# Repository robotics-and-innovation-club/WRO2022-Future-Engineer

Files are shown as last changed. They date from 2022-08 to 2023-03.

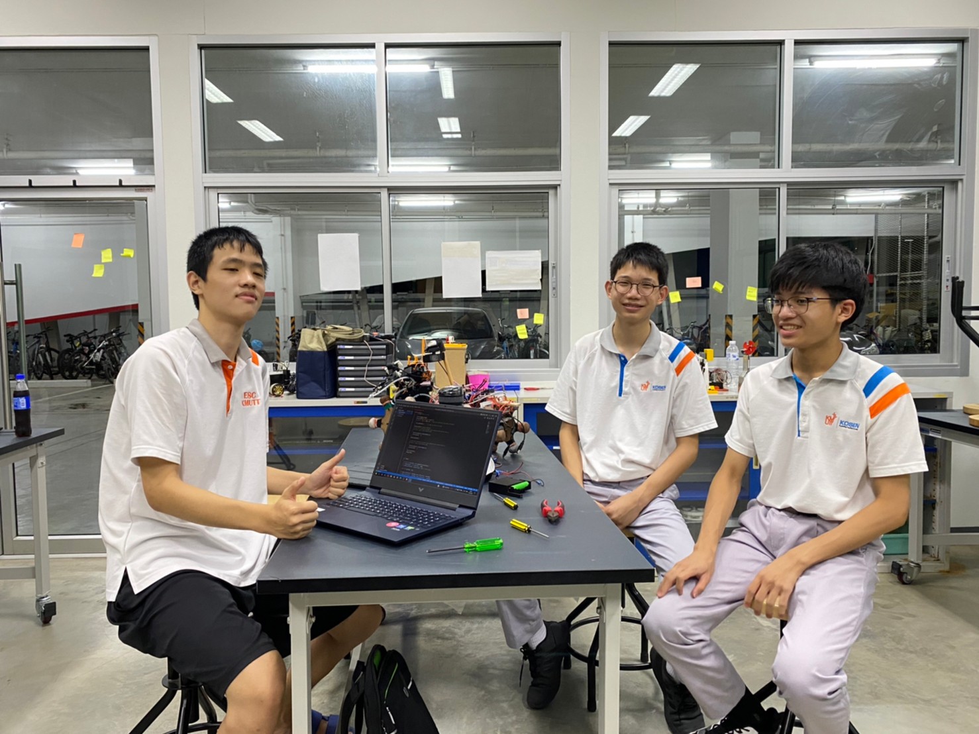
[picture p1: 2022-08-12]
team-photos/Funny Photo.jpg

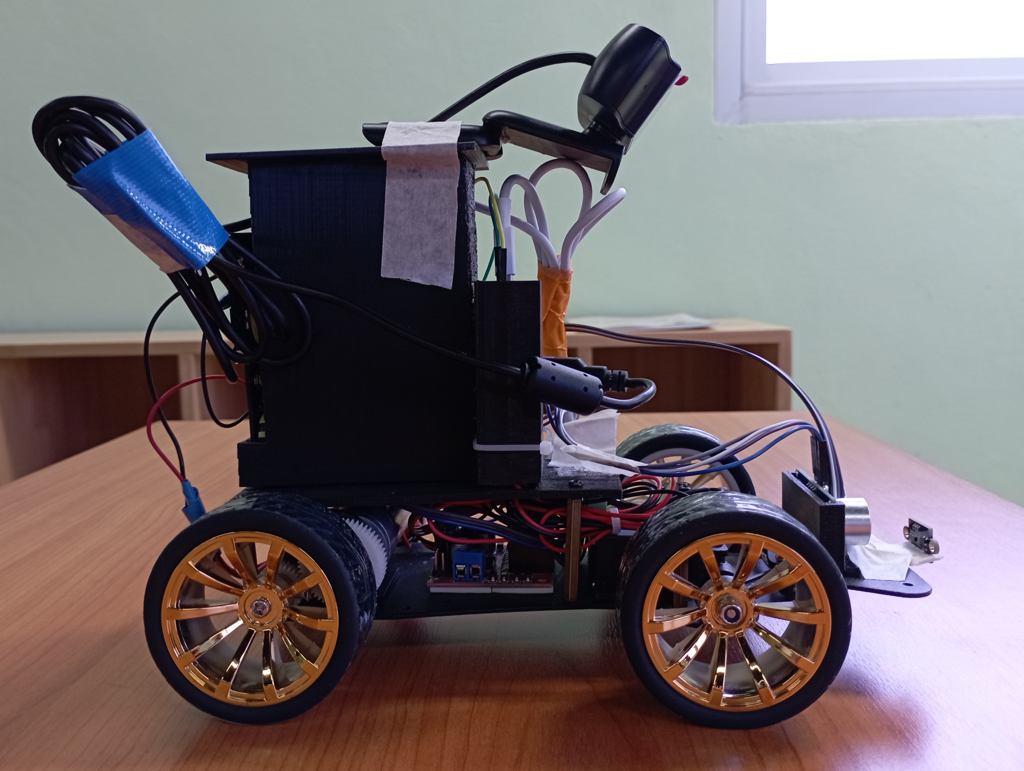
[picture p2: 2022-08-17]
vehicle-photos/LEFT.jpg

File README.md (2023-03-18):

# Teams from the Robotics and Innovation Club (RIC)
Darunsikkhalai School (Engineering-Science Classroom & KOSEN KMUTT)

## Our Teams
- Kitsada      Doungjitjaroen  Supervisor / Assistance
- Theekhathat  Wongsubsantati  Member
- Theeraphat   Thongbai        Member
- Nattavee     Sunitsakul      Member

## Contents
- ```models``` include 3D-printed replicas of our car's parts.
- ```src``` contain all of the source code of our vehicle. (Python source code)
- ```schemes``` contains all of our schematic diagrams of the electromechanical parts that show all the parts (motors, electronics, and other electromechanical components) used in the vehicle and their connections.
- ```team-photos``` contains two images of our team (an official photo and one funny photo with all of our team members)
- ```vehicle-photos``` contains 6 photos of the vehicle (from every side, from top and bottom)
- ```video``` contains a link to a video on YouTube that demonstrates how our vehicle operates.

## Introduction
How can we control electronics with the Raspberry Pi 4? We use the GPIOZERO library to control the GPIO pins of the Raspberry Pi, so that we can control motors and servos. Thanks to the hardware PWM of the Raspberry Pi 4 Model B, it helps our servo motor turn at an accurate angle as well as control the speed of the motor accurately.

How can we make the car go straight? We use computer vision to detect the environment. Then we can approximate how far the car is from the environment.

We use HSV colour space, and then we find a range of colours in the field that we will see in the competition. We need to configure the upper and lower colors, such as orange, blue, black, and white.

In the side environment, we use our upper and lower HSV of black walls. We find the filter black pixels in the upper and lower range. After that, we will filter the blue line out of this frame so that it has more accuracy in detaching black pixels of color.

On the floor, we use the same method to detect blue and orange lines. We use the upper and lower range of orange and blue colors that we found, then detect if the area has more than one consistency value that we researched to filter the error detection.

We also use computer vision to detect which turn we want when the car is initial. This method helps us go in a clockwise and counter-clockwise direction. without a struggle in any direction.

Next, we use data that our computer vision detected before to make a decision to turn left or right by how many degrees or go straight with some speed. We also use data from our 2 distance sensors to help make decisions more accurately on when to turn hard and when to stop.

Then, we use the computer vission to detect the line and count how many rounds have passed by, so that we can control how many rounds we want the car to drive automatically.

### How to use
1. Prepare all electronic parts and machanic parts
2. Bring your Raspberry Pi 4 Model B, then [install Raspberry Pi OS (64-bit)](https://github.com/robotics-and-innovation-club/WRO2022-Future-Engineer#how-to-install-raspberry-pi-os)
3. Install Python 3.10.5 and pip3
4. Install all of required libraries (GPIOZERO, openCV, adafruit-circuitpython-vl53l0x)
5. [Enable I2C](https://github.com/robotics-and-innovation-club/WRO2022-Future-Engineer/blob/main/README.md#how-to-enable-i2c)
6. Enable Hardware PWM, by run ```sudo systemctl enable pigpiod``` in terminal.
7. git clone this github repository
8. open terminal and run ```cd WRO2022-FUTURE-ENGINEER/src```
9. run ```sudo python main1.py``` or ```sudo python main2.py```

## Software / Program
All of our source code is in ```src``` directory. All of it is Python source code.

Our software mainly uses GPIOZERO and openCV libraries. With GPIOZERO, we use this library to control servo motors and motors. With openCV, we use this library to do computer vision.

```Actuator.py``` we use hardware PWM of the Raspberry Pi 4 Model B, so we need to run ```sudo systemctl enable pigpiod``` to enable hardware PWM to work (every time the Raspberry Pi boots it will start pigpiod services automatically).

```Radar_Distance_Sensor.py``` we use for getting the distance from the Radar Distance Sensor (VL53L0X). In the VL53L0X class, the get_distance method will return the distance in centimeters.

### How to install Raspberry Pi OS
1. go to ```https://www.raspberrypi.com/software/``` website, then if you are Windows user click```Download for Windows```, if you are macOS user click```Download for macOS```, if you are Ubuntu use click```Download for Ubuntu for x86```, but if you are Raspberry Pi OS user, type ```sudo apt install rpi-imager``` in a Terminal window.
2. Choose OS, In this car we use ```Raspberry Pi OS (64-bit)```
3. Choose Storage (SD-CARD)
4. (OPTIONAL) If you prefer to configure anything before installing the OS to storage, you can configure it by click ```Advcance Option``` or the gear sign (on the bottom left of the window).
5. Click ```Write```

### How to enable I2C
1. open terminal
2. type ```sudo raspi-config```
3. select ```Interfacing Options```
4. select ```I2C```
5. select ```<Yes>```
6. select ```Ok```
7. If it requires you to reboot, select ```<Yes>```

## Models
- ```base with nut hole.STL``` The STL file is the base component that will be used to attach the electronic mounter component to the vehicle base.
- ```step down mount.STL``` This is the component that will be mounted to the electronic mounter base. This is used to insert a step-down DC to DC converter.

## Electronic
- Raspberry Pi 4 Model B (OS : Raspberry Pi OS 64-bits) 1 ea.
- Battery (18650 Lithium-ion battery) 3 ea.
- USB HD Camera (720p camera) 1 ea.
- DC to DC step down converter (from 9VDC-36VDC to 5VDC-3A) 1 ea.
- Motor Driver Module (L298N) 1 ea.
- DC Motor (12VDC) 1 ea.
- Servo Motor (MG996R) 1 ea.
- Ultrasonic sensor 1 ea.
- Radar Distance sensor 1 ea.

All electronic components are wired as shown in schematic diagrams in ```schemes``` directory.
In ```schemes``` directory, ```diagram_fritzing.png``` is the property diagram from the Fritzing program, and ```Easy Diagram.pdf``` is an easy diagram of our circuit.

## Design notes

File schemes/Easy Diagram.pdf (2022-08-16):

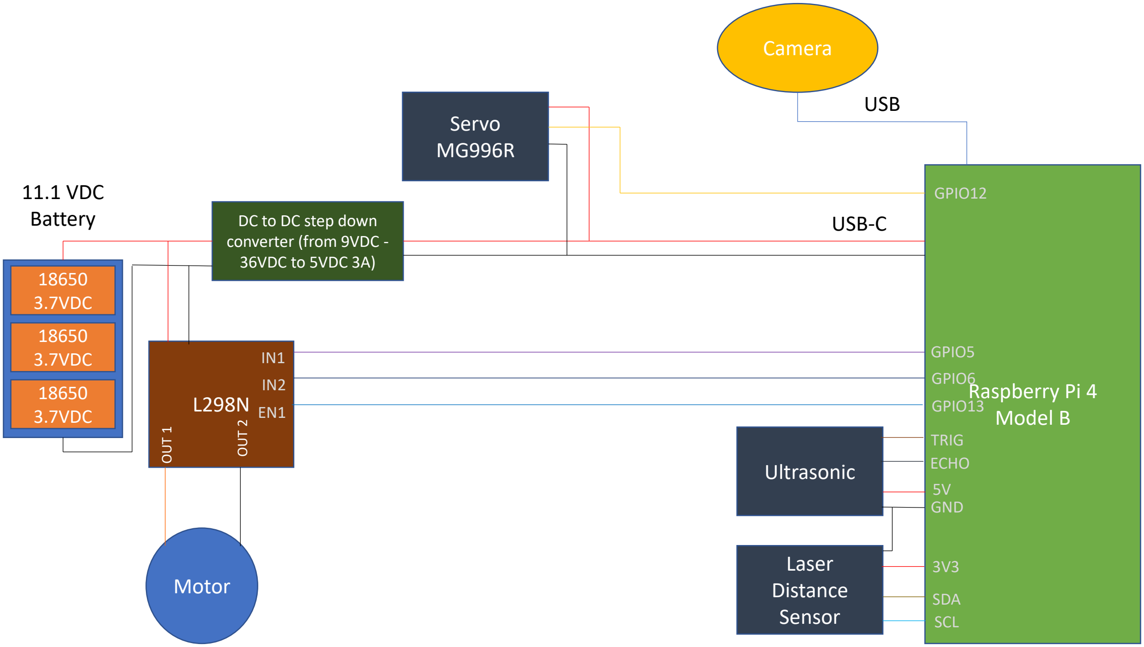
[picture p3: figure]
Raspberry Pi; Model; Camera; USB; 18650 3.7VDC; DC to DC step down converter (from 9VDC; 36VDC to 5VDC 3A); 11.1 VDC Battery; Motor; Servo MG996; OUT 1; OUT 2; GPIO12; GPIO5; GPIO6; GPIO13; Ultrasonic; Laser Distance Sensor; GND; SDA SCL; TRIG ECHO

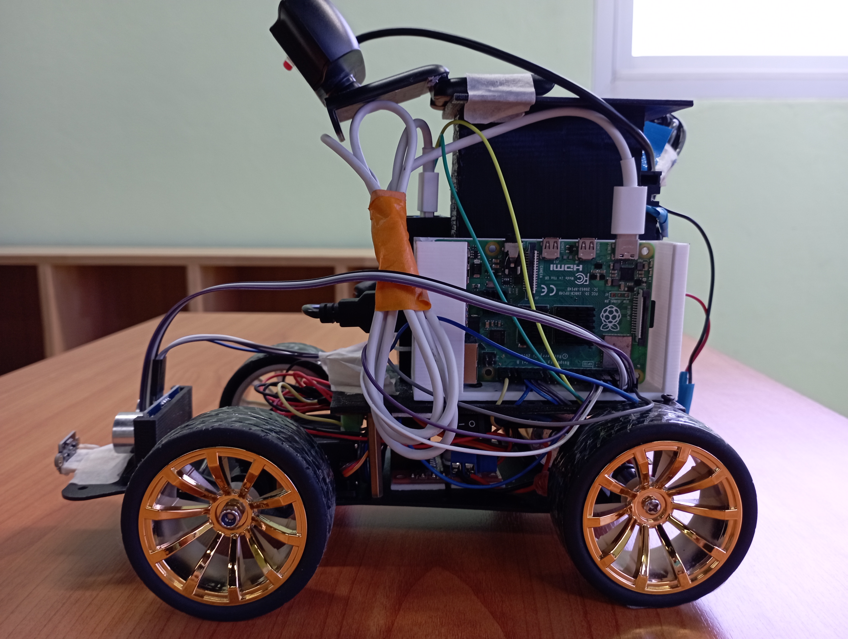
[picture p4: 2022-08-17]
vehicle-photos/RIGHT.jpg

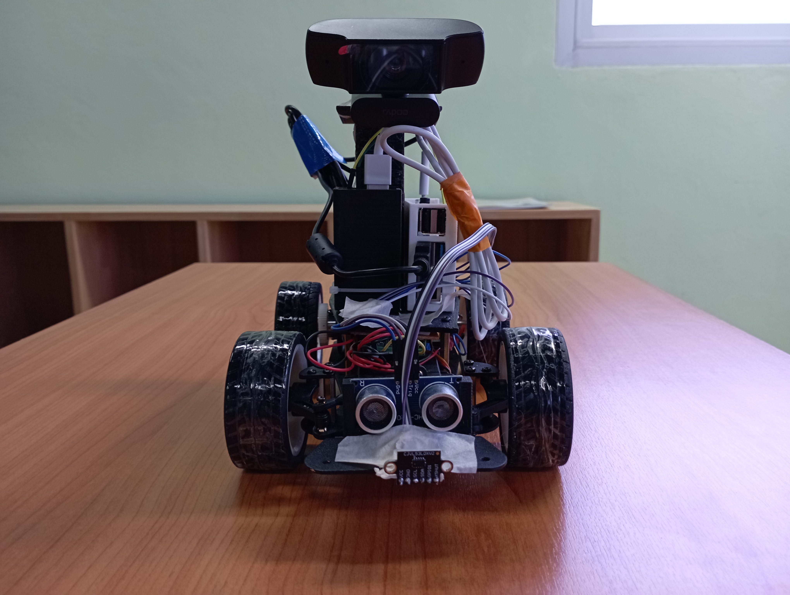
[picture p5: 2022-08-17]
vehicle-photos/FRONT.jpg

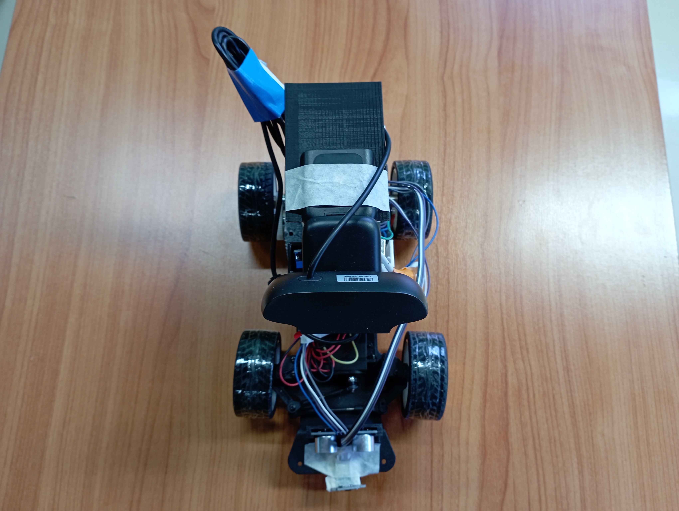
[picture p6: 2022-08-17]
vehicle-photos/TOP.jpg

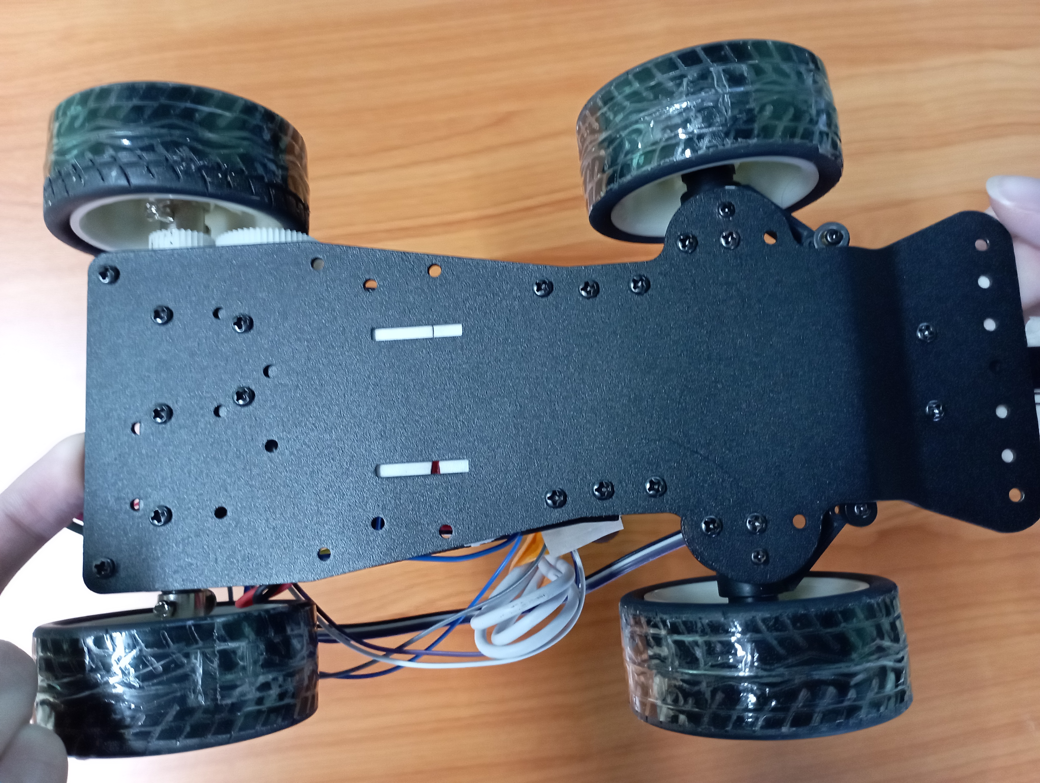
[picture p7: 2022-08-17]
vehicle-photos/BOTTOM.jpg

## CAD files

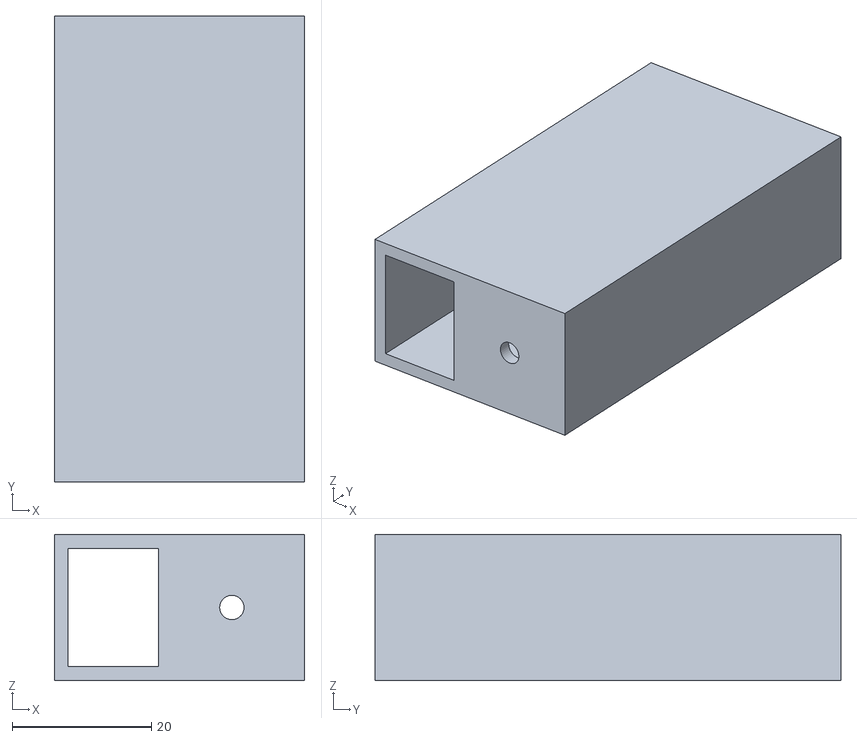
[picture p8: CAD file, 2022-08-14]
models/step down mount.STL
36.0 x 67.0 x 21.0

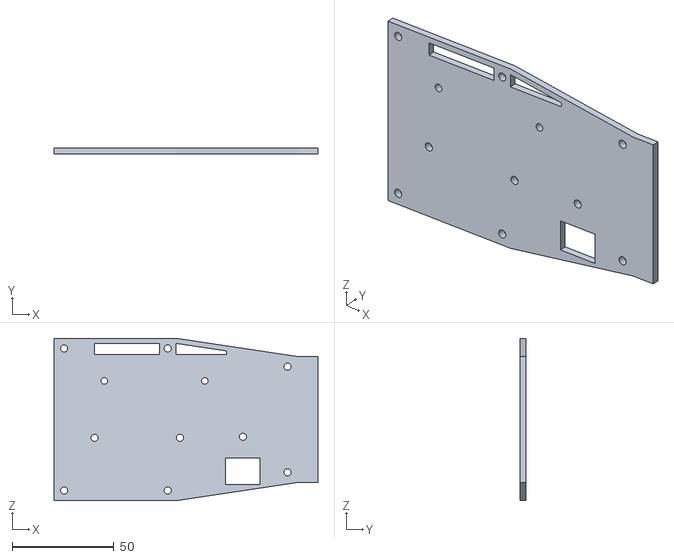
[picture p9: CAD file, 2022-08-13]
models/base with nut hole.STL
130.0 x 3.00 x 80.0

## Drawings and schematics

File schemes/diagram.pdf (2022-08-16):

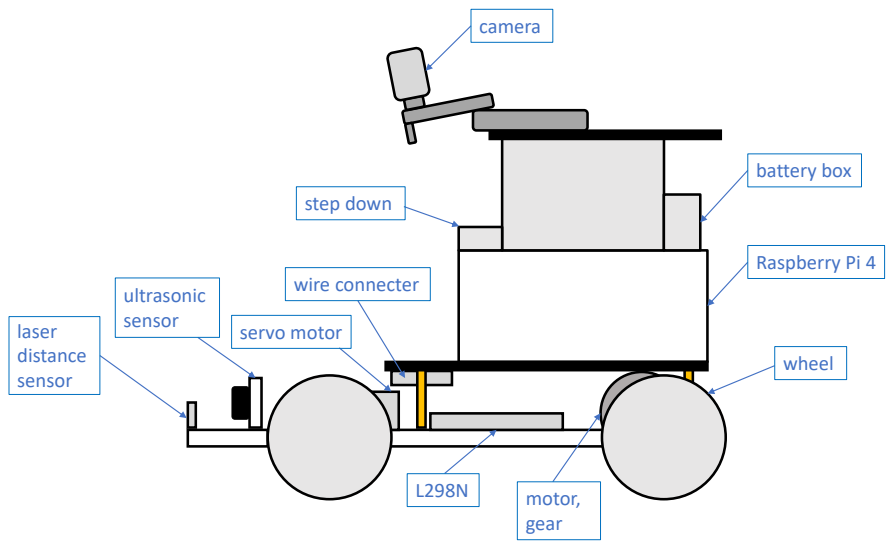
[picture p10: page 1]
camera; Raspberry Pi 4; battery box; wheel; motor, gear; servo motor; ultrasonic sensor laser; distance sensor; wire connecter; step down

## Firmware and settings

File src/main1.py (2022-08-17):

import gpiozero as gpio
from gpiozero.pins.pigpio import PiGPIOFactory
import cv2
import numpy as np
import time
from gpiozero import DistanceSensor
from Actuator import *
from Ultrasonic import *

safe = 40
e_old = None
count = 0

lowBl = np.array([111, 80, 78]) 
upBl = np.array([179, 255, 255])

lowOl = np.array([0, 38, 145]) 
upOl = np.array([179, 255, 255])

lowgreen = np.array([52, 72, 107])  
upgreen = np.array([92, 134, 196])  

lowyellow = np.array([27, 167, 99]) 
upyellow = np.array([42, 255, 231])

lowred = np.array([0, 135, 50])  
upred = np.array([8, 255, 255])

lowred1 = np.array([165, 135, 50]) 
upred1 = np.array([180, 255, 255])

lowfl = np.array([100, 0, 151])
upfl = np.array([179, 255, 255])

lowwall = np.array([0, 0, 0])
upwall = np.array([179, 255, 50])

lowbitb = np.array([100,150,0])
upbitb = np.array([140,255,255])

xright21, yright21 = 430, 230
xright22, yright22 = 640, 270

xleft11, yleft11 = 0, 230
xleft12, yleft12 = 210, 270

xright41, yright41 = 590, 205
xright42, yright42 = 640, 230

xleft31, yleft31 = 0, 205
xleft32, yleft32 = 50, 230

xBl1, yBl1 = 320, 345
xBl2, yBl2 = 390, 405

xOl1, yOl1 = 250, 345
xOl2, yOl2 = 320, 405

xObj1, yObj1 = 110, 140
xObj2, yObj2 = 530, 330

xAbove1 , yAbove1 = 251, 20
xAbove2 , yAbove2 = 389, 190

#[0, 54, 2], [179, 255, 255]

def black_line(frame):  
    global xright21, yright21, xright22, yright22, xAbove1, yAbove1, xAbove2, yAbove2, left_track, right_track, mid_track,yleft11,yleft12, xleft11,xleft12
   
    datb1 = frame[yleft11:yleft12, xleft11:xleft12]
  
    dat1 = cv2.GaussianBlur(datb1, (5, 5), cv2.BORDER_DEFAULT)
 
    hsv = cv2.cvtColor(dat1, cv2.COLOR_BGR2HSV)

    mask1 = cv2.inRange(hsv, lowwall, upwall )

    bmask = cv2.inRange(hsv.copy(), lowOl, upOl)

    bmask1 = cv2.inRange(hsv.copy(), lowbitb, upbitb)

    bmask2 = cv2.inRange(hsv.copy(), lowfl, upfl)

    bmask3 = cv2.bitwise_or(bmask, bmask1)

    bmask4 = cv2.bitwise_or(bmask3, bmask2)

    maskd1 = cv2.bitwise_and(mask1, cv2.bitwise_not(bmask4))

    gray11 = cv2.cvtColor(maskd1, cv2.COLOR_GRAY2BGR)
   
    frame[yleft11:yleft12, xleft11:xleft12] = gray11


    contoursd1,_ = cv2.findContours(
        maskd1, cv2.RETR_TREE, cv2.CHAIN_APPROX_NONE)  
    track1 = 0
    max1 = 0
    for contorb1 in contoursd1:
        
        x1, y1, w1, h1 = cv2.boundingRect(contorb1)
        a1 = cv2.contourArea(contorb1)  
       
        if a1 > 200 and a1 / (h1 * w1) > 0.3 and a1 > max1:
            track1 = h1 * (x1 + w1) 
            max1 = a1  
            cv2.rectangle(datb1, (x1, y1), (x1 + w1, y1 + h1),
                          (255, 0, 0), 2)  

   
    datb2 = frame[yright21:yright22, xright21:xright22]
    
    dat2 = cv2.GaussianBlur(datb2, (9, 9), cv2.BORDER_DEFAULT)
    
    hsv2 = cv2.cvtColor(dat2, cv2.COLOR_BGR2HSV)

    mask2 = cv2.inRange(hsv2, lowwall, upwall )

    bmask_ = cv2.inRange(hsv2.copy(), lowOl, upOl)

    bmask1_ = cv2.inRange(hsv2.copy(), lowbitb, upbitb)

    bmask2_ = cv2.inRange(hsv2.copy(), lowfl, upfl)

    bmask3_ = cv2.bitwise_or(bmask_, bmask1_)

    bmask4_ = cv2.bitwise_or(bmask3_, bmask2_)

    maskd2 = cv2.bitwise_and(mask2, cv2.bitwise_not(bmask4_))

    gray12 = cv2.cvtColor(maskd2, cv2.COLOR_GRAY2BGR)
   
    frame[yright21:yright22, xright21:xright22] = gray12

    contoursd2,_ = cv2.findContours(
        maskd2, cv2.RETR_TREE, cv2.CHAIN_APPROX_NONE) 
    track2 = 0
    max2 = 0
    for contorb2 in contoursd2:
       
        x1, y1, w1, h1 = cv2.boundingRect(contorb2)
        a1 = cv2.contourArea(contorb2)  
        
        if a1 > 200 and a1 / (h1 * w1) > 0.3 and a1 > max2:
            track2 = h1 * (250 - x1)  
            max2 = a1 
            cv2.rectangle(datb2, (x1, y1), (x1 + w1, y1 + h1),
                          (255, 0, 0), 2)
    
    
   
    # datb3 = frame[yAbove1:yAbove2, xAbove1:xAbove2]
    
    # dat3 = cv2.GaussianBlur(datb3, (9, 9), cv2.BORDER_DEFAULT)
    
    # hsv3 = cv2.cvtColor(dat3, cv2.COLOR_BGR2HSV)

    # mask3 = cv2.inRange(hsv3, lowwall, upwall )

    # bmask__ = cv2.inRange(hsv3.copy(), lowOl, upOl)

    # bmask1__ = cv2.inRange(hsv3.copy(), lowbitb, upbitb)

    # bmask2__ = cv2.inRange(hsv3.copy(), lowfl, upfl)

    # bmask3__ = cv2.bitwise_or(bmask__, bmask1__)

    # bmask4__ = cv2.bitwise_or(bmask3__, bmask2__)

    # maskd3 = cv2.bitwise_and(mask3, cv2.bitwise_not(bmask4__))

    # gray13 = cv2.cvtColor(maskd3, cv2.COLOR_GRAY2BGR)
   
    # frame[yAbove1:yAbove2, xAbove1:xAbove2] = gray13

    # contoursd3,_ = cv2.findContours(
    #     maskd3, cv2.RETR_TREE, cv2.CHAIN_APPROX_NONE) 
    # track3 = 0
    # max3 = 0
    # for contorb3 in contoursd3:
       
    #     x1, y1, w1, h1 = cv2.boundingRect(contorb3)
    #     a1 = cv2.contourArea(contorb3)  
        
    #     if a1 > 200 and a1 / (h1 * w1) > 0.3 and a1 > max2:
    #         track3 = h1 *(x1-251+w1)
    #         max3 = a1 
    #         cv2.rectangle(datb3, (x1, y1), (x1 + w1, y1 + h1),
    #                       (255, 0, 0), 2)
            
    
    left_track = int(track1/98)
    right_track = int(track2/98)
    # mid_track = -(int(track3/100))


def blue_line(frame): 
    global max2, yBl1, yBl2, xBl1, xBl2, Blueline, timeB
    line = frame[yBl1:yBl2, xBl1:xBl2]
    cv2.rectangle(frame, (xBl1, yBl1), (xBl2, yBl2),
                  (0, 0, 255), 2) 
    dat1 = cv2.GaussianBlur(line, (5, 5), cv2.BORDER_DEFAULT)
   
    hsv = cv2.cvtColor(dat1, cv2.COLOR_BGR2HSV)
   
    mask = cv2.inRange(hsv, lowBl, upBl)
   
    contours,_ = cv2.findContours(
        mask, cv2.RETR_TREE, cv2.CHAIN_APPROX_NONE)  
    max2 = 0
    for contor in contours: 
     
        x1, y1, w1, h1 = cv2.boundingRect(contor)
        a1 = cv2.contourArea(contor) 
        if a1 > 100: 
            cv2.rectangle(line, (x1, y1), (x1 + w1, y1 + h1),
                          (0, 255, 0), 2) 
            timeB = time.time()
            
            Blueline = True
         


def orange_line(frame): 
    global max2, yOl1, yOl2, xOl1, xOl2, Orangeline, timeO
   
    line = frame[yOl1:yOl2, xOl1:xOl2]
    cv2.rectangle(frame, (xOl1, yOl1), (xOl2, yOl2), (0, 0, 255),
                  2)  
    dat1 = cv2.GaussianBlur(line, (5, 5), cv2.BORDER_DEFAULT)
  
    hsv = cv2.cvtColor(dat1, cv2.COLOR_BGR2HSV)
   
    mask = cv2.inRange(hsv, lowOl, upOl)
   
    rmask = cv2.inRange(hsv.copy(), lowObjred, upObjred)
   
    rmask2 = cv2.inRange(hsv.copy(), lowObjred1, upObjred1)
   
    rmask3 = cv2.bitwise_or(rmask, rmask2)
  
    mask2 = cv2.bitwise_and(mask, cv2.bitwise_not(rmask3))
   
    contours,_ = cv2.findContours(
        mask2, cv2.RETR_TREE, cv2.CHAIN_APPROX_NONE)  
    max2 = 0
    for contor in contours:
       
        x1, y1, w1, h1 = cv2.boundingRect(contor)
        a1 = cv2.contourArea(contor) 
        if a1 > 100: 
            cv2.rectangle(line, (x1, y1), (x1 + w1, y1 + h1),
                          (0, 255, 0), 2)
            timeO = time.time()
            Orangeline = True

LowBlue2 = np.array([111, 80, 78])  
UpBlue2 = np.array([124, 164, 141])

LowOrange2 = np.array([0, 38, 145])  
UpOrange2 = np.array([13, 223, 192])


def track_line(frame):
    global LowBlue2, UpBlue2, LowOrange2, UpOrange2, Blue_Line, Orange_Line
    trackline = frame[270:530,100:540]
    cv2.rectangle(frame, (100, 270), (540, 530), (0, 0, 255), 2)
    dat1 = cv2.GaussianBlur(trackline, (5, 5), cv2.BORDER_DEFAULT)
    hsv1 = cv2.cvtColor(dat1.copy(), cv2.COLOR_BGR2HSV)
    hsv2 = cv2.cvtColor(dat1.copy(), cv2.COLOR_BGR2HSV)
    maskdB = cv2.inRange(hsv1,LowBlue2,UpBlue2)
    maskdO = cv2.inRange(hsv2,LowOrange2,UpOrange2)
    contoursdB, _ = cv2.findContours(maskdB, cv2.RETR_TREE, cv2.CHAIN_APPROX_NONE)
    contoursdO, _ = cv2.findContours(maskdO, cv2.RETR_TREE, cv2.CHAIN_APPROX_NONE)
   
    for contorb1 in contoursdO:
        x, y, w, h = cv2.boundingRect(contorb1)
        a1 = cv2.contourArea(contorb1)
        if a1 > 500:
            cv2.rectangle(trackline, (x, y), (x + w, y + h), (0, 0, 255), 2)
            Orange_Line = True
                     
    for contorb1 in contoursdB:
            x, y, w, h = cv2.boundingRect(contorb1)
            a1 = cv2.contourArea(contorb1)
            if a1 > 500:
                cv2.rectangle(trackline, (x, y), (x + w, y + h), (255, 0, 0), 2)
                Blue_Line = True

def count_line(frame):
    global LowOrange2, UpOrange2, timeO
    trackline = frame[270:530,100:540]
    dat1 = cv2.GaussianBlur(trackline, (5, 5), cv2.BORDER_DEFAULT)
    hsv1 = cv2.cvtColor(dat1.copy(), cv2.COLOR_BGR2HSV)
    maskdO = cv2.inRange(hsv1,LowOrange2,UpOrange2)
    contoursdO, _ = cv2.findContours(maskdO, cv2.RETR_TREE, cv2.CHAIN_APPROX_NONE)
   
    for contorb1 in contoursdO:
        x, y, w, h = cv2.boundingRect(contorb1)
        a1 = cv2.contourArea(contorb1)
        if a1 > 100:
            cv2.rectangle(trackline, (x, y), (x + w, y + h), (0, 0, 0), 2)
            timeO = time.time()
            

def blue_tr():
    global e, ul, ul_need_turn
    if e==0 and ul_need_turn:
        car.left(40,25)
    elif e<0:
        car.left(15,15)
    elif e>40:
        car.right(15,15)

def orange_tr():
    global e, ul, ul_need_turn
    if e==0 and ul_need_turn:
        car.right(40,25)
    elif e>0:
        car.right(15,15)
    elif e<-40:
        car.left(15,15)


Orange_Line = False
Blue_Line = False

car = Car()
car.right(30,0)
cap = cv2.VideoCapture(0)
ultrasonic = gpio.DistanceSensor(echo=27, trigger=17,max_distance=5)
ul_need_turn = None
last_ul_need_turn = None
cam_near_right = None
cam_near_right = None
init = True
direction = None
turn_cycle = 0
timeO_old = 0
timeO = 0

sen = VL53L0X()

while init:
    car.straight_forward(15)
    _, frame = cap.read()
    frame = cv2.resize(frame,(640,480))
    track_line(frame)
    if Blue_Line and not Orange_Line:
        direction = True
        init = False
    elif Orange_Line and not Blue_Line:
        direction = False
        init = False
    cv2.imshow('frame', frame)
    cv2.waitKey(1)


while 1:
     
    _, frame = cap.read()
    frame = cv2.resize(frame,(640,480))
   
    black_line(frame)
    track_line(frame)
    count_line(frame)
    # if Blueline and Orangeline:
    #     count+=1
    #     Blueline = False
    #     Orangeline = False
    #     print(count)
    # Orangeline = False
    # print(Blueline,Orangeline)

    e = left_track-right_track
    print(e)
    if -5 < e < 5:
        e=0
        
    ul = sen.get_distance()+10
    
    car.straight_forward(22) #เซฟโซนปลอดภัยๆ
    if ul<55:
          ul_need_turn = True
    
    else :
          ul_need_turn = False

    if direction:
        blue_tr()
    else:
        orange_tr()
        
    if timeO-timeO_old>1.5:
        turn_cycle+=1
        print("turn cycle", turn_cycle)

    timeO_old = timeO

    # if ul_need_turn:
    #     ang = 40
    #     spe = 25
    #     if direction:
    #         car.left(ang,spe)
    #     else:
    #         car.right(ang,spe)
    # if not ul_need_turn and last_ul_need_turn:
    #     turn_cycle += 1
    #     print("turn cycle", turn_cycle)
    # if last_ul_need_turn != ul_need_turn:
    #     last_ul_need_turn = ul_need_turn

    if turn_cycle>=12:
        if direction:
           car.left(25,25)
           time.sleep(1.5)
           car.stop()
           break
        else:
           car.right(25,25)
           time.sleep(1.5)
           car.stop()
           break
            

    # if count==12:
    #     time.sleep(2)
    #     car.stop()
    #     break
    cv2.imshow('frame', frame)
    if cv2.waitKey(1) & 0xFF == ord('q'):
        car.stop()
        break

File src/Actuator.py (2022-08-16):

import gpiozero as gpio
from gpiozero.pins.pigpio import PiGPIOFactory
import time

from Radar_Distance_Sensor import *

class Servo:
    def __init__(self, pin: int, servo_angle: float = 180, min_angle: float = None, max_angle: float = None):
        """create servo class

        Args:
            pin (int): Servo signal pin
        """
        factory = None
        # factory = PiGPIOFactory()
        self._pin = pin
        self._servo_angle = servo_angle
        self._min_angle = min_angle
        self._max_angle = max_angle
        if self._min_angle is None:
            self._min_angle = 0
        if self._max_angle is None:
            self._max_angle = servo_angle
        self._servo = gpio.AngularServo(pin=self._pin, initial_angle=None, min_angle=0, max_angle=self._servo_angle, min_pulse_width=0.5 /
                                        1000, max_pulse_width=2.5 / 1000, frame_width=20 / 1000, pin_factory=factory)

    def __q_lerp(self, value: float, ease: float):
        """convert a linear value to an ease value according to the smoothness (0->1)"""
        return pow(value, ease)/(pow(value, ease)+pow(1-value, ease))

    def __variable_limit(self, val: float, min_n: float, max_n: float):
        """limit value to min_n and max_n

        Args:
            val (float): value to limit
            min_n (float): min value
            max_n (float): max value

        Returns: val, state
            val, float: value after the limit
            state, bool: if value is out of limit return False else return True
        """
        if val < min_n:
            return min_n, False
        elif val > max_n:
            return max_n, False
        else:
            return val, True

    def __return_servo_position_on_state(self, from_position: float, to_position: float, percent: float, ease: float):
        """convert a linear value to an ease value according to the smoothness (0->1)"""
        size = to_position - from_position
        percent, state = self.__variable_limit(
            val=percent, min_n=0, max_n=50)
        percent /= 100
        first_state = from_position+self.__q_lerp(percent, ease)*size
        last_state = from_position+self.__q_lerp(1-percent, ease)*size
        final_state = to_position
        return first_state, last_state, final_state

    def set_angle(self, angle: float):
        """set servo angle (-1 mean disable servo)

        Args:
            angle (float): to servo angle

        Returns: state, now angle
            state, bool: if servo angle that limit in init (min_angle and max_angle) is exceeded return False else return True
            now angle, float: now servo angle in degrees
        """
        # disable servo if angle is -1
        if angle == -1:
            return True, self.disble()

        now = self.get_angle()
        if now == -1:
            now = 0
        to = self.__return_servo_position_on_state(
            from_position=now, to_position=angle, percent=20, ease=2)
        for i in to:
            self._servo.angle, state = self.__variable_limit(
                val=i, min_n=self._min_angle, max_n=self._max_angle)
        return state, self.get_angle()

    def get_angle(self):
        """get now servo angle (-1 mean servo is disable)

        Returns:
            float: servo angle in degrees
        """
        angle = self._servo.angle
        if angle is None:
            angle = -1
        return angle

    def disble(self):
        """disable servo
        """
        self._servo.value = None


class Motor:
    def __init__(self, IN1: int, IN2: int, EN: int, dir1: bool):
        """motor control

        Args:
            IN1 (int): IN1 pin
            IN2 (int): IN2 pin
            EN (int): EN pin (enable pin)
            dir (bool): if True mean no needed to flip the direction (forward is forward), if False mean need to flip the direction (forward is backward)
        """
        factory = None
        # factory = PiGPIOFactory()
        self._motor_pin = {"IN1": IN1, "IN2": IN2, "EN": EN}
        self._motor = gpio.Motor(
            forward=self._motor_pin["IN1"], backward=self._motor_pin["IN2"], enable=self._motor_pin["EN"], pwm=True, pin_factory=factory)
        self.dir = dir1

    def forward(self, speed: int):
        """move the motor forward with dir 

        Args:
            speed (int): 0-100 slow to fast
        """
        speed = speed/100
        if self.dir:
            self._motor.forward(speed)
        else:
            self._motor.backward(speed)

    def backward(self, speed: int):
        """move the motor backward with dir 

        Args:
            speed (int): 0-100 slow to fast
        """
        speed = speed/100
        if self.dir:
            self._motor.backward(speed)
        else:
            self._motor.forward(speed)

    def stop(self):
        """stop the motor
        """
        self._motor.stop()
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

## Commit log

2022-08-13 [NEW] base with nut hole part
2022-08-13 [NEW] Models part
    [base with nut hole.STL]
2022-08-13 [NEW] motor file
2022-08-14 [UPDATE] step down mount detail and file
    [step down mount.STL]
2022-08-15 [UPDATE] servo control
2022-08-16 [UPDATE] motor
2022-08-16 [UPDATE] Actuator code of car
2022-08-16 [NEW] Radar Distance Sensor code
2022-08-16 [UPDATE] details of Actuator.py
2022-08-16 [NEW] how to install raspberry pi os
2022-08-16 [UPDATE] how to use + [NEW] how to Enable I2c
